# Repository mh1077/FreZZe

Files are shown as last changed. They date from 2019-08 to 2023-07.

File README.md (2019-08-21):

# FreZZe
Fremo Zeit Zeichenempfänger

Das ist ein Zeitzeichen Empfänger für das MRClock Protokoll. Es empfängt MRClock Datentelegramme (Multicast) auf dem WLAN. Der Zeitzeichenempfänger 
wandelt die empfangenen Telegramme um, sodass eine Nebenuhrlinie mit mehreren Uhren betrieben werden kann. Eine Anzeige für Uhr läuft / steht kann realisiert werden, z.B. mit einer rot/grün Ampel aus der Fertigungstechnik.

Viel Spass beim Nachbauen

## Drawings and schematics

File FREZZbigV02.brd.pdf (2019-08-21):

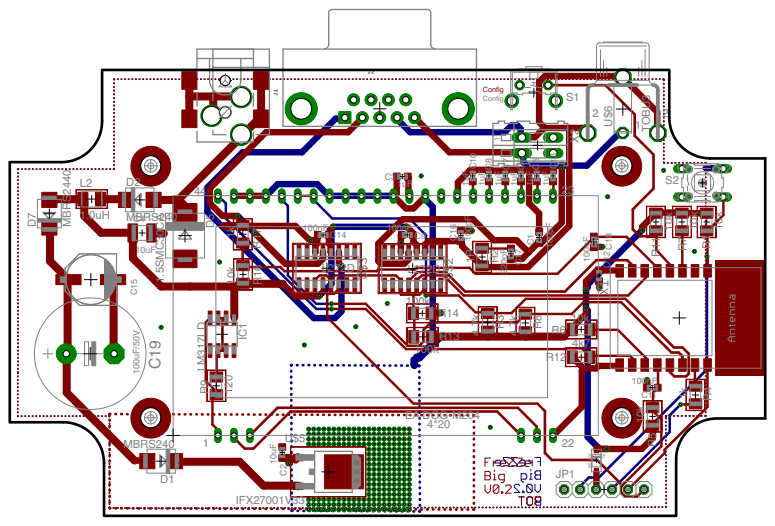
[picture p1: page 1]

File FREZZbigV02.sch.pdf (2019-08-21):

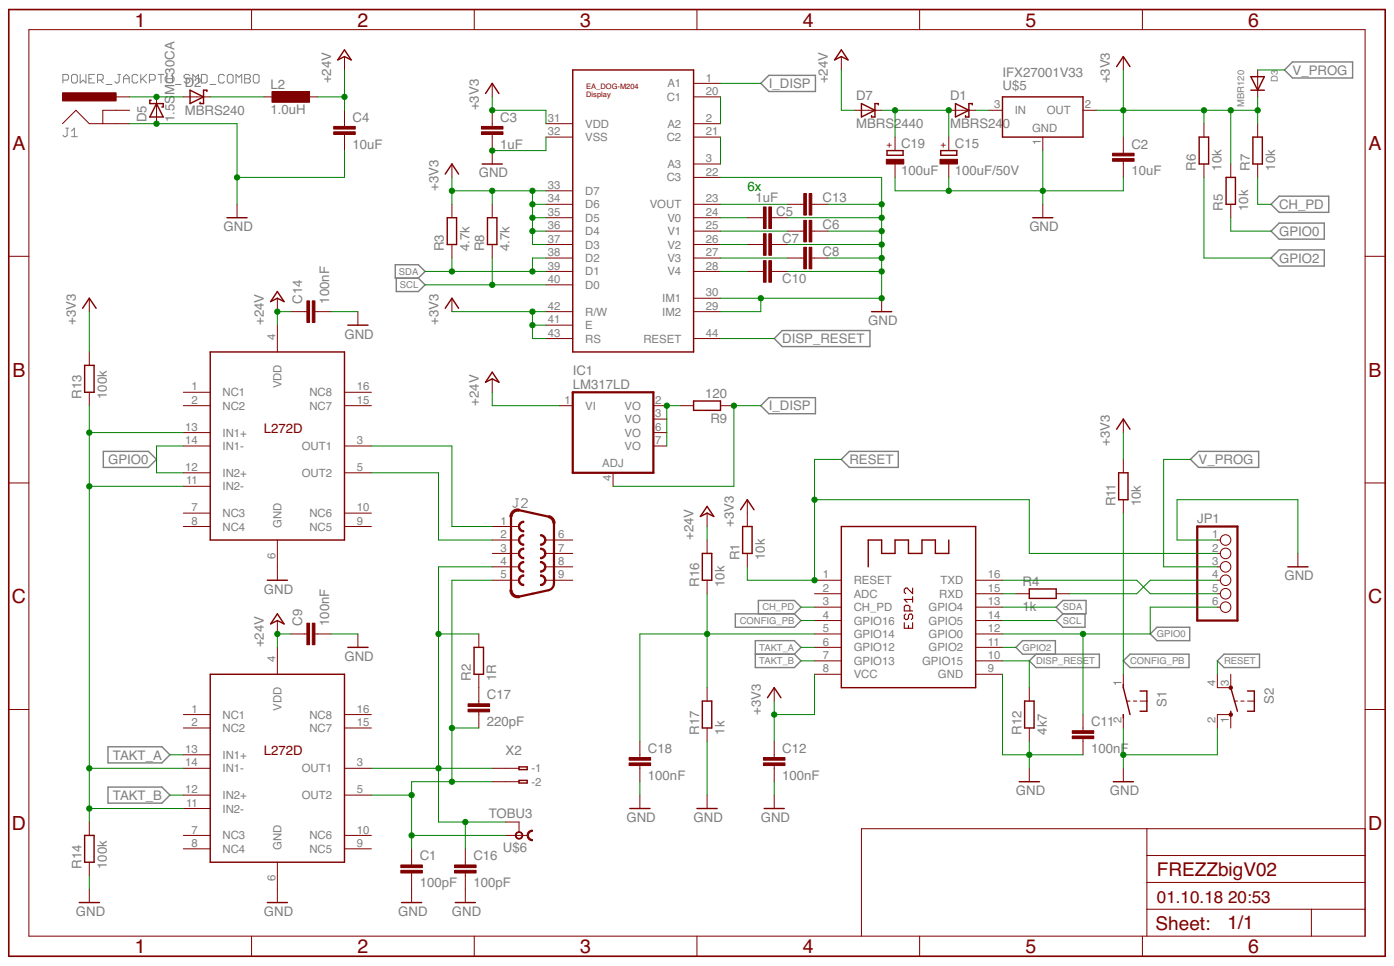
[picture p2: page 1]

34
35 | 24 | C5
36 | 25 | | C6

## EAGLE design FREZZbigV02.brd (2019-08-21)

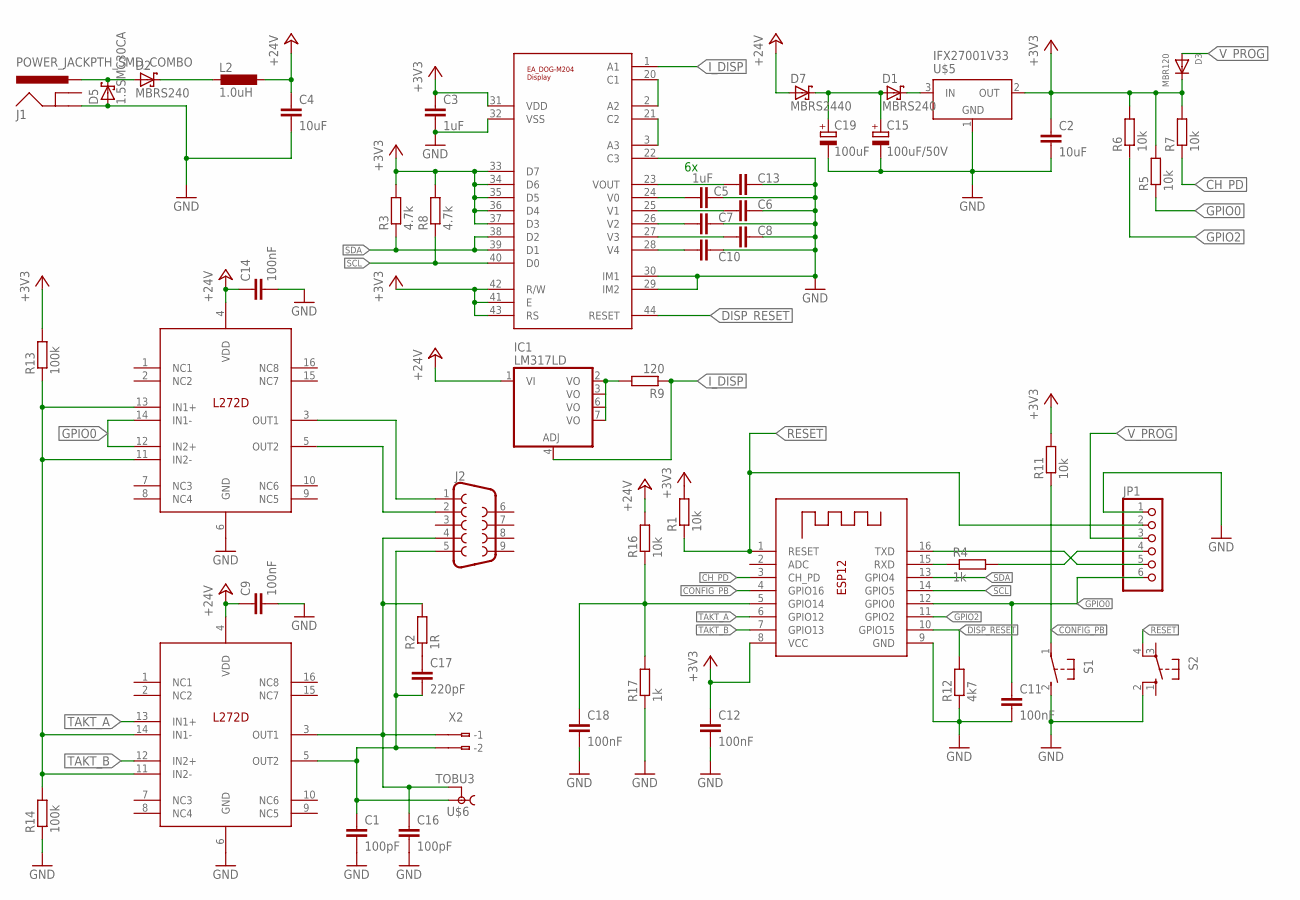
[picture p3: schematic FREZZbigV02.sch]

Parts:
C1, C16: 100pF; C0603K
C2: 10uF; C0603K
C3, C5, C6, C7, C8, C10, C13: 1uF; C0603K
C4: 10uF; C1210K
C9, C11, C12, C14, C18: 100nF; C0603K
C15: 100uF/50V; PANASONIC_F
C17: 220pF; C0603K
C19: 100uF; E7,5-18
D1, D2: MBRS240; SMB
D3: MBR120; SOD-123
D5: 1.5SMC30CA; SMC
D7: MBRS2440; SMB
IC1: LM317LD; SO08
J1: POWER_JACKPTH_SMD_COMBO; POWER_JACK_COMBO
J2: DB9FEMALE; DB9
JP1: PINHD-1X6; 1X06
L2: 1.0uH; L3230M
R1, R5, R6, R7, R11, R16: 10k; M1206
R2: 1R; M1206
R3, R8: 4.7k; M1206
R4, R17: 1k; M1206
R9: 120; M1206
R12: 4k7; M1206
R13, R14: 100k; M1206
S1: 31-XX; B3F-31XX
S2: 10-XX; B3F-10XX
U$1: EA_DOG-M204-DISPLAY; E_DOG-M204_DISPLAY
U$2, U$3: L272D; SO16
U$5: IFX27001V33; TO252
U$6: TOBU3; TOBU3-REICHELT
X1: ESP-12
X2: 233-102

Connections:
$N122: D1.C, U$5.3 (IN)
+3V3: C2.1, C3.1, C12.1, D3.C, R1.2, R3.2, R5.2, R6.2, R7.2, R8.2, R11.2, R13.2, U$1.31 (VDD), U$1.33 (D7), U$1.34 (D6), U$1.35 (D5), U$1.36 (D4), U$1.37 (D3), U$1.41 (E), U$1.42 (R/W), U$1.43 (RS), U$5.2 (OUT), X1.8 (VCC)
+24V: C4.1, C9.1, C14.1, D7.A, IC1.1 (VI), L2.1, R16.2, U$2.4 (VDD), U$3.4 (VDD)
CH_PD: R7.1, X1.3 (CH_PD)
CONFIG_PB: R11.1, S1.1, X1.4 (GPIO16)
DISP_RESET: R12.2, U$1.44 (RESET), X1.10 (GPIO15)
GND: C1.2, C2.2, C3.2, C4.2, C5.1, C6.1, C7.1, C8.1, C9.2, C10.1, C11.2, C12.2, C13.1, C14.2, C15.-, C16.2, C18.2, C19.-, D5.A, J1.GND@1 (GND), JP1.1, R12.1, R14.1, R17.1, S1.2 (S), S2.2 (S1), U$1.22 (C3), U$1.29 (IM2), U$1.30 (IM1), U$1.32 (VSS), U$2.6 (GND), U$3.6 (GND), U$5.1 (GND), X1.9 (GND)
GPIO0: C11.1, JP1.6, R5.1, U$3.12 (IN2+), U$3.14 (IN1-), X1.12 (GPIO0)
GPIO2: R6.1, X1.11 (GPIO2)
I_DISP: IC1.4 (ADJ), R9.1, U$1.1 (A1)
unnamed: JP1.5, X1.16 (TXD)
unnamed: JP1.4, R4.2
unnamed: R4.1, X1.15 (RXD)
unnamed: C13.2, U$1.23 (VOUT)
unnamed: D2.A, D5.C, J1.POWER (PWR)
unnamed: C5.2, U$1.24 (V0)
unnamed: D2.C, L2.2
unnamed: C15.+, C19.+, D1.A, D7.C
unnamed: C17.1, R2.1
unnamed: C16.1, J2.4, R2.2, U$2.3 (OUT1), U$6.2, U$6.2@1 (2), U$6.2@2 (2), X2.B1 (B-1)
unnamed: C6.2, U$1.25 (V1)
unnamed: C1.1, C17.2, J2.5, U$2.5 (OUT2), U$6.1, X2.B2 (B-2)
unnamed: C7.2, U$1.26 (V2)
unnamed: C8.2, U$1.27 (V3)
unnamed: C10.2, U$1.28 (V4)
unnamed: U$1.3 (A3), U$1.21 (C2)
unnamed: U$1.2 (A2), U$1.20 (C1)
unnamed: IC1.2 (VO), IC1.3 (VO), IC1.6 (VO), IC1.7 (VO), R9.2
unnamed: J2.1, U$3.3 (OUT1)
unnamed: J2.2, U$3.5 (OUT2)
unnamed: R13.1, R14.2, U$2.11 (IN2-), U$2.14 (IN1-), U$3.11 (IN2-), U$3.13 (IN1+)
RESET: JP1.2, R1.1, S2.4 (P1), X1.1 (RESET)
SCL: R8.1, U$1.40 (D0), X1.14 (GPIO5)
SDA: R3.1, U$1.38 (D2), U$1.39 (D1), X1.13 (GPIO4)
SHDN: C18.1, R16.1, R17.2, X1.5 (GPIO14)
TAKT_A: U$2.13 (IN1+), X1.6 (GPIO12)
TAKT_B: U$2.12 (IN2+), X1.7 (GPIO13)
V_PROG: D3.A, JP1.3

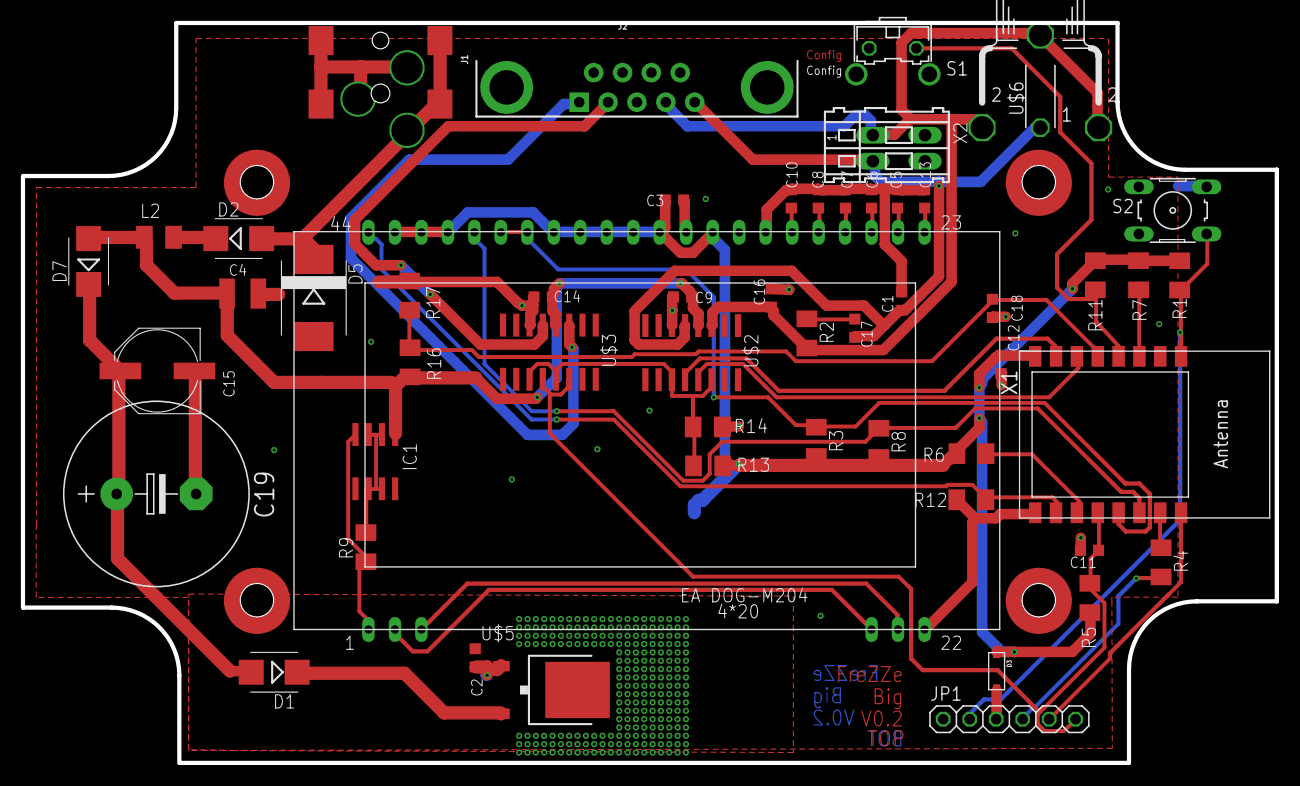
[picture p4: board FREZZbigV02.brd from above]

Board: 2 copper layers, 120.3 x 71.0 mm, 53 parts (0 on the bottom side), 38 nets.

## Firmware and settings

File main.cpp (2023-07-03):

//FreZZe mit EA-Display DOGM204 I2C
//Läuft ab LP V0.2
//Software erstellt 02. September 2017
//Version 1.1 - 06. Januar 2020
//Version 1.2 - 06. April 2020 - Unterstützung für NTP (Normalzeit) eingebaut
//Version 1.3 - 8. Mai 2022 - Wechsel auf Platform IO und Visual Studio Code
//              2. Juli 23 - Letzte Tests V1.3 und Freigabe
//              Achtung! Für den PufferC C15 bzw. C15 wird neu 1000uF benötigt, sonst funktioniert das automatische 
//                       Abspeichern bei Spannungsverlust nicht mehr zuverlässig!

#define VERSION "V1.3"

//Includes Librarys:
#include <Arduino.h>
#include "FS.h"                   //this needs to be first, or it all crashes and burns...
#include <LittleFS.h>

#include "TickerScheduler.h"      //Ticker

#include <ESP8266WiFi.h>          //https://github.com/esp8266/Arduino

//needed for library
#include <ESP8266WebServer.h>
#include <WiFiManager.h>          //https://github.com/tzapu/WiFiManager

#include <ArduinoJson.h>          //https://github.com/bblanchon/ArduinoJson
#include <StreamUtils.h>

//needed for NTP 
#include <TimeLib.h>
#include <WiFiUdp.h>
#include <Timezone.h>             //by Jack Christensen, not included in the Arduino IDE !!!

// Communication for the Display
#include <Wire.h>

#include <String>

//Eigene Funktionen
#include "FreZZe.h"

//Defines for Pins
#include "FreZZe_PINS.h"

//Defines für Zeiten
#include "FreZZe_TIMES.h"

//Defines für das Display
#define I2C_ADRESS 0x3D
#define DISPLAYKONTRAST   10      //nach Test ein guter Wert

//Variablen für die LED Anzeige
int LEDStatus = 0;                //LED Status wird durch das Programm gemäss den oben angegebenen Defines gesetzt und durch die Task LED() wird die LED angesteuert
int LEDStatusIntern = 0;          //LED Status intern für die LED Routine
int LEDStatusCounter = 0;         //LED Status Counter zum zählen bis zum nächsten Statuswechsel
int LEDPeriodCounter = 0;         //Dient als Zähler für das LEDaus vorbereiten (Periodenlänge LED an)....

//define your default values here, if there are different values in config.json, they are overwritten.
char mrc_multicast[40] = "239.50.50.20";
char mrc_port[6] = "2000";

//char array for the protokollhandler 
char c_clock_hour[15] = "03";
char c_clock_minute[15] = "02";
char c_clock_sek[15] = "04";
char c_time[15] = "0";
char c_speed[15] = "0";

//Strings 
String esp_chipid;

//Displaybuffer
char SBuffer[4][80] = {{ "11111111111111111111" },{ "22222222222222222222" },{ "33333333333333333333" },{ "44444444444444444444" }};

//TEMP Variable for Display
char ctempd[200];
String stempd;

//VARIABLEN für die IP-Addressenübernahme
String sIPAddressinformertime;    //Letzte bekannte IP-Adresse, welche akzeptiert wurde
String sIPAddressjustrecieved;    //aktuelle empfangene IP-Adresse
String sIPAddresstemprecieved;    //diese IP-Addresse wird nach einer Zeit akzeptiert und zu sIPAddressinformertime übernommen
int iCounterIPAddress = 0;        //Counter zur Übernahme einer neuen IP-Adresse

//Daten aus dem Protokoll
int  clock_h = 0;   // Sollzeit Stunde
int  clock_m = 0;   // Sollzeit Minute
int  clock_s = 0;   // Sollzeit Sekunde
int  clock_speed = 1; //Zeitverkürzung
bool clock_aktiv = false; //Läuft die Uhr oder steht sie? 

int  tochter_h = 0; // Istzeit auf der 12h Tochteruhr (Stunden)
int  tochter_m = 0; // Istzeit auf der 12h Tochteruhr (Minuten)

int  itelecnt = 0; //Zähler wird als Watchdog für den Telegrammempfang, wird beim Telegrammenpfang 
                   //auf den TELECNTSTART Wert gesetzt und in jeder Schleife um ein reduziert.
                   //ist er 0, wird die Ampel auf rot geschaltet.
#define TELECNTSTART 6000 //Zeitbasis = der Delay() Wert in der Loop Schleife! 1 entspricht 10ms bei Delay(10)

//NTP Variablen
char ntpserver[40] = "ntp.metas.ch";         //NTPServer
unsigned int localPort = 8888;               // local port to listen for UDP packets
const int timeZone = 0;                      // UTC
double dCounterToNTP;                        //if no MRCLOCK telegramm is recieved, the conter gets decressed, on ZERO the NTP time is displayed
const int NTP_PACKET_SIZE = 48;              // NTP time is in the first 48 bytes of message
byte packetBufferNTP[NTP_PACKET_SIZE];       //buffer to hold incoming & outgoing packets

//Timezone
//Central European Time (Frankfurt, Paris)
TimeChangeRule CEST = { "CEST", Last, Sun, Mar, 2, 120 };     //Central European Summer Time
TimeChangeRule CET = { "CET ", Last, Sun, Oct, 3, 60 };       //Central European Standard Time
Timezone CE(CEST, CET);
TimeChangeRule *tcr;        //pointer to the time change rule, use to get the TZ abbrev
time_t utc, local;
time_t prevDisplay = 0;     // when the digital clock was displayed

//Statemaschine für TochterUhrStellen Routine
int  SM = 0;                  // Statemaschine Status
int  SMC = 0;                 // Statemaschine Counter
bool FlagTUStellen;           // Flag ist gesetzt, falls die Tochteruhr einen Tick machen soll
bool FlagTUStellglied;        // Flag wiederspiegelt den Ausgang des TU Stellglieds

//Rücksetztaste
bool FlagButtonPresed = false;
int  CounterButtonPressed;

//Tickerscheduler Objekt

TickerScheduler ts(10);

//flag for saving data
bool shouldSaveConfig = false;

//flag for sleep mode 
bool sleep = false;
bool flag_message_recieved = true;
bool flag_wrongIP = false;

//flag for clock ticks
bool bClockBad = true;  //true on startup, until one falid Clockmessage war recieved

//WifiUDP Class
WiFiUDP wifiUDPMRC;     //für MRClock Telegramme
WiFiUDP wifiUDPNTP;     //für NTP Telegramme

const int MRC_PACKET_SIZE = 2024; // NTP time stamp is in the first 48 bytes of the message

char packetBuffer[ MRC_PACKET_SIZE ]; //buffer to hold incoming and outgoing packets

int nLength = 0;

int time_hour = 0;

int time_minute = 0;

unsigned long millisAfterISR = 0;

//WiFiManager
  //Das Object wird auch noch im LOOP benötigt um die Config zu löschen.... 
  WiFiManager wifiManager;
  //Die beiden Parameter werden durch ein Callback verändert, deswegen müssen sie Global definiert sein
  WiFiManagerParameter custom_time_hour();
  WiFiManagerParameter custom_time_minute();

void setup() {
  // put your setup code here, to run once:
  Serial.begin(115200);
  Serial.println("Starting up!");

  LED(LEDOff);               // Am Anfang ist die LED aus....

  //ChipID?
  esp_chipid = String(ESP.getChipId());

  //Identify
  Serial.print("Tochteruhrempfänger TUE ");
  Serial.print(VERSION);
  Serial.print(" ESP - ChipID = ");
  Serial.println(esp_chipid); 

  Serial.println("Configuring Pins and Interrupts");

  //Variablen initialisieren
  FlagTUStellen = false;  //FlagTUStellen initialisieren
  SM = 1;
  SMC = 0;                //Statemaschine für die Taktausgabe initialisieren
  
  delay(500);

  //Display initialisieren
  //I2C Pins konfigurieren

  pinMode(DISP_RESET, OUTPUT);
  digitalWrite(DISP_RESET, LOW);
  delay(500);
  digitalWrite(DISP_RESET, HIGH);
  delay(500);
  
  //I2C initialisieren, Display init
  Wire.begin();

  Wire.setClock(200000L);
  
  LCD_Init();

  delay(10);

  // Buffer          "1   5    10   15  19"
  strcpy(SBuffer[0], "FREMO MRCLOCK       ");
  strcpy(SBuffer[1], "Reciever        ");
  strcat(SBuffer[1], VERSION); 
  strcpy(SBuffer[2], "                    ");
  strcpy(SBuffer[3], "INIT.               ");

  LCD_Refresh();

  delay(1000);

  //WiFi.setAutoReconnect(false);
  WiFi.persistent(true); // Wird gebraucht damit das Flash nicht zu oft beschrieben wird.
  WiFi.setAutoReconnect(true);
  
  //Pins konfigurieren
  //GPIO #12 (TaktA)
  //GPIO #13  (TaktB)
  //GPIO #16 (Input für Config Pushbutton) Bei MRC_REC = 5!
  //GPIO #2 = blue LED on ESP
  //GPIO #14 = Interrupt für Spannungseinbruch -> Interrupt wird an der fallenden Flanke ausgelöst
  //GPIO #15 Reset des Displays
  //GPIO #0 Ampel grün/rot

  pinMode(TAKTA, OUTPUT);
  pinMode(TAKTB, OUTPUT);
  pinMode(CONFIGPB, INPUT);
  pinMode(BLED, OUTPUT);
  pinMode(AMPEL, OUTPUT);

  digitalWrite(AMPEL, HIGH);  //Ampel auf Rot stellen

  //Konfiguration des InterruptPINs 
  //Sobald eine + Spannung gemessen wird, wird der Interrupt aktiviert, wird LOW gemessen, dann ist der Interrupt deaktiviert
  pinMode(INT, INPUT);
  delay(10);

  if(digitalRead(INT) == HIGH){     //Interrupt wird aktiviert
    Serial.println("Interrupteingang verdrahtet, wird benutzt!");
    attachInterrupt(digitalPinToInterrupt(INT), ISRSaveData, FALLING);
  }
  else{
    Serial.println("Interrupteingang ist nicht verdrahtet, wird nicht benutzt!");
    pinMode(INT, INPUT_PULLUP);
  }

  digitalWrite(BLED, HIGH);

  ts.add(5, 10, [&](void*) { LEDTS(); }, nullptr, false);

  if(ts.enable(5)){
    Serial.println("LEDTS() = 5 enabled");
  }

  LED(LEDBlinkOnce);         // LED einen Flash blinken -> 1. Blinkimpuls

  //clean FS, for testing
  //SPIFFS.format();
  //SPIFFS.remove("/config.json");
  //SPIFFS.remove("/config2.json");
  
  //read configuration from FS json
  Serial.println("mounting FS...");

  // Falls das Filesystem noch nicht formatiert ist, wird es hier automatisch gemacht.
  if(LittleFS.begin()){
    Serial.println("FS ok!");
  } else {
    LittleFS.format();
    Serial.println("FS formated");
  }

  LED(LEDBlinkOnce);     // LED einen Flash blinken  -> 2. Blinkimpuls

  //Filesystem mounten und Datei suchen, wenn Datei nicht vorhanden dann Neuerstellung
  if (LittleFS.begin()) {
    Serial.println("mounted file system");
    if (LittleFS.exists("/config.json")) {
      //file exists, reading and loading
      Serial.println("reading config file");
      File configFile = LittleFS.open("/config.json", "r");
      if (configFile) {
        Serial.println("opened config file");
        //size_t size = configFile.size();

        DynamicJsonDocument jsonDocument(2048);

        // ArduinoJson 6
        ReadLoggingStream loggingStream(configFile, Serial);
        DeserializationError error = deserializeJson(jsonDocument, configFile);
        Serial.print("\n-deserializeJson() -> output:");
        Serial.print(error.c_str());

        /*
        // Allocate a buffer to store contents of the file.
        std::unique_ptr<char[]> buf(new char[size]);

        configFile.readBytes(buf.get(), size);
        DynamicJsonDocument jsonDocument(size);

        Serial.println("ConfigFile:");
        Serial.println(configFile.read());

        // ArduinoJson 6
        DeserializationError error = deserializeJson(jsonDocument, configFile);
        */
        
        if (!error) 
        {
          Serial.println("\nparsed json =>  ");

          /*
          strcpy(ntpserver, jsonDocument["ntp_server"]);
          strcpy(mrc_multicast, jsonDocument["mrc_multicast"]);
          strcpy(mrc_port, jsonDocument["mrc_port"]);
          strcpy(c_clock_hour, jsonDocument["clock_hour"]);
          strcpy(c_clock_minute, jsonDocument["clock_minute"]);
          if(jsonDocument["FlagTUStellglied"] == "true")
          {
            FlagTUStellglied = true;
            digitalWrite(TAKTA, LOW);
            digitalWrite(TAKTB, LOW);
            Serial.print("FlagTUStellglied = true");
          } else {
            FlagTUStellglied = false;
            digitalWrite(TAKTA, HIGH);
            digitalWrite(TAKTB, HIGH); 
            Serial.print("FlagTUStellglied = false");
          }

          */

          JsonVariant jvntpserver = jsonDocument["ntp_server"];
          if (!jvntpserver.isNull()) {
            Serial.print(" ntpserver=");
            Serial.print(jvntpserver.as<const char*>());
            strcpy(ntpserver, jvntpserver.as<const char*>());
          } else {
            strcpy(ntpserver, "ntp.metas.ch");
            Serial.print(" no value => ntp.metas.ch");
          }

          JsonVariant jvmrc_multicast = jsonDocument["mrc_multicast"];
          Serial.print(", mrc_multicastadress=");
          if (!jvmrc_multicast.isNull()) {
            Serial.print(jvmrc_multicast.as<const char*>());
            strcpy(mrc_multicast, jvmrc_multicast.as<const char*>());
          } else {
            strcpy(mrc_multicast, "239.50.50.20");
            Serial.print(" no value => 239.50.50.20");
          }

          JsonVariant jvmrc_port = jsonDocument["mrc_port"];
          Serial.print(", mrc_port=");
          if (!jvmrc_port.isNull()) {
            Serial.print(jvmrc_port.as<const char*>());
            strcpy(mrc_port, jvmrc_port.as<const char*>());
          } else {
            strcpy(mrc_port, "2000");
            Serial.print("no value => 2000");
          }

          JsonVariant jvc_clock_hour = jsonDocument["clock_hour"];
          Serial.print(", clock_hour=");
          if (!jvc_clock_hour.isNull()) {
            Serial.print(jvc_clock_hour.as<int>());
            itoa(jvc_clock_hour, c_clock_hour, 10);
            //strcpy(c_clock_hour, jvc_clock_hour.as<char*>());
          } else {
            strcpy(c_clock_hour, "0");
            Serial.print("no value => 0");
          }

          JsonVariant jvc_clock_minute = jsonDocument["clock_minute"];
          Serial.print(", clock_minute=");
          if (!jvc_clock_minute.isNull()) {
            Serial.print(jvc_clock_minute.as<int>());
            itoa(jvc_clock_minute, c_clock_minute, 10);
            //strcpy(c_clock_minute, jvc_clock_minute.as<char*>());
          } else {
            strcpy(c_clock_minute, "0");
            Serial.print("no value => 0");
          }

          JsonVariant jvc_flagTUStellglied = jsonDocument["FlagTUStellglied"];
          Serial.print(", FlagTUStellglied=");
          if(!jvc_flagTUStellglied.isNull()){
            if(jsonDocument["FlagTUStellglied"] == true){
              FlagTUStellglied = true;
              digitalWrite(TAKTA, LOW);
              digitalWrite(TAKTB, LOW);
              Serial.print("true");
            }else{
              FlagTUStellglied = false;
              digitalWrite(TAKTA, HIGH);
              digitalWrite(TAKTB, HIGH); 
              Serial.print("false");
            }
          }
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
void loop() 
{
  // loop checks for:
  // - MRCLOCK Telegramm, or
  // - NTP 
  // MRCLOCK has priority to NTP telegramms, if there were no MRCLOCK Telegramm for WaittimeNTPSync [seconds] then, the 
  // Slaveclock is syncronised to NTP Clock until the first MRCLOCK telegramm comes in...
  
  // If a MRCLOCK Telegramm is recieved:
  if (int packetsize = wifiUDPMRC.parsePacket()) 
  {
    dCounterToNTP = WaittimeNTPSync;           // Counter updaten
    Serial.println("@.");
    flag_wrongIP = false;
    // We've received a packet, read the data from it
    wifiUDPMRC.read(packetBuffer, packetsize); // read the packet into the buffer

    //Search for Message like "clock=10:32:35"
    for(unsigned long i=0; i < sizeof(packetBuffer); i++)
    {
      if( packetBuffer[i] == 'c' &&
          packetBuffer[i+1] == 'l' &&
          packetBuffer[i+2] == 'o' &&
          packetBuffer[i+3] == 'c' &&
          packetBuffer[i+4] == 'k' &&
          packetBuffer[i+5] == '=')
      {
        c_time[0] = packetBuffer[i+6];
        c_time[1] = packetBuffer[i+7];
        c_time[2] = packetBuffer[i+8];
        c_time[3] = packetBuffer[i+9];
        c_time[4] = packetBuffer[i+10];
        c_time[5] = packetBuffer[i+11];
        c_time[6] = packetBuffer[i+12];
        c_time[7] = packetBuffer[i+13];
        c_time[8] = packetBuffer[i+14];
            
        // Time Char Array zerlegen
        bool clear_h = true;
        bool clear_m = false;
        bool clear_s = false;
            
        for(int ii=0; ii < 15; ii++)
        {
          if( !clear_h && !clear_m && clear_s)
          {                
            if( c_time[ii] == 0)
            {
              clear_m = false;
              clear_s = false;
              c_clock_hour[ii] = ' ';
              c_clock_minute[ii] = ' ';
              c_clock_sek[ii] = ' ';
            } else {
              c_clock_hour[ii] = ' ';
              c_clock_minute[ii] = ' ';
              c_clock_sek[ii] = c_time[ii];
            }
          }
          if( !clear_h && clear_m && !clear_s) 
          {                
            if( c_time[ii] == ':')
            {
              clear_m = false;
              clear_s = true;
              c_clock_hour[ii] = ' ';
              c_clock_minute[ii] = ' ';
              c_clock_sek[ii] = ' ';
            } else {
              c_clock_hour[ii] = ' ';
              c_clock_minute[ii] = c_time[ii];                  
              c_clock_sek[ii] = ' ';
            }
          }
          if( clear_h && !clear_m && !clear_s)
          {                
            if( c_time[ii] == ':')
            {
              clear_h = false;
              clear_m = true;
              c_clock_hour[ii] = ' ';
              c_clock_minute[ii] = ' ';
              c_clock_sek[ii] = ' ';
            } else {
              c_clock_hour[ii] = c_time[ii];
              c_clock_minute[ii] = ' ';
              c_clock_sek[ii] = ' ';
            }
          }
        }
  
        clock_h = atoi(c_clock_hour);
        clock_m = atoi(c_clock_minute);
        clock_s = atoi(c_clock_sek);

        Serial.print("Empfangenes Zeitzeichen:");
        Serial.print(clock_h);
        Serial.print(":");
        Serial.print(clock_m);
        Serial.print(":");
        Serial.println(clock_s);
      }
    }
     
    //Search for Message like "speed=5"
    for(unsigned long i=0; i < sizeof(packetBuffer); i++)
    {
      if( packetBuffer[i] == 's' &&
          packetBuffer[i+1] == 'p' &&
          packetBuffer[i+2] == 'e' &&
          packetBuffer[i+3] == 'e' &&
          packetBuffer[i+4] == 'd' &&
          packetBuffer[i+5] == '=')
      {
        if(packetBuffer[i+6] == '\n' || packetBuffer[i+6] == '\r')
        {
          c_speed[0] = '\0';
        } else c_speed[0] = packetBuffer[i+6];
        if(packetBuffer[i+7] == '\n' || packetBuffer[i+7] == '\r')
        {
          c_speed[1] = '\0';
        } else c_speed[1] = packetBuffer[i+7];
        if(packetBuffer[i+8] == '\n' || packetBuffer[i+8] == '\r')
        {
          c_speed[2] = '\0';
        } else c_speed[2] = packetBuffer[i+8];
        if(packetBuffer[i+9] == '\n' || packetBuffer[i+9] == '\r')
        {
          c_speed[3] = '\0';
        } else c_speed[3] = packetBuffer[i+9];
        
        c_speed[4] = '\0';

        Serial.print("Speed=");
        Serial.println(c_speed);

        Serial.print("Speed_int=");
        clock_speed = atoi(c_speed);
        Serial.println(clock_speed);
      }
    }

    //Search for Message like "active=yes|no"
    for(unsigned long i=0; i < sizeof(packetBuffer); i++)
    {
      if( packetBuffer[i] == 'a' &&
          packetBuffer[i+1] == 'c' &&
          packetBuffer[i+2] == 't' &&
          packetBuffer[i+3] == 'i' &&
          packetBuffer[i+4] == 'v' &&
          packetBuffer[i+5] == 'e' &&
          packetBuffer[i+6] == '=')
      {
        if( packetBuffer[i+7] == 'y' &&
            packetBuffer[i+8] == 'e' &&
            packetBuffer[i+9] == 's')
        {
          clock_aktiv = true;
          digitalWrite(AMPEL, LOW);  //Ampel auf Grün stellen
          itelecnt = TELECNTSTART;
        } else {
          digitalWrite(AMPEL, HIGH);  //Ampel auf Rot stellen
          clock_aktiv = false;
        }
          
        if(clock_aktiv)
        {
          Serial.println("Uhr läuft!");
        } else Serial.println("Uhr steht!");
      }
    }

    // recieving one message!
    Serial.println("; Ende der Message");
    flag_message_recieved = true;
  }

  //Stimmt die Anzeige auf der Ampel?
  if(clock_aktiv)
  {
    if(!itelecnt)
    {
      digitalWrite(AMPEL, HIGH);  //Ampel auf Rot stellen
      clock_aktiv = false;
    } else itelecnt--;
  }
  
  // Ist der Taster gedrückt?
  ConfigButton();

  //Soll auf NTP-Zeitzeichenempfang umgeschaltet werden?
  if(dCounterToNTP == 0)
  {
    //jetzt wird die NTP Zeit an der Tochteruhr angezeigt...
    if (timeStatus() != timeNotSet) 
    {
      if (now() != prevDisplay) 
      { 
        //update the display only if time has changed
        prevDisplay = now();

        local = CE.toLocal(now(), &tcr);
        
        Serial.print("Hour=");
        Serial.print(hour(local), DEC);
        Serial.print("Minute=");
        Serial.print(minute(local), DEC);
        Serial.print("Seconds=");
        Serial.println(second(local), DEC);
  
        clock_h = hour(local);
        clock_m = minute(local);
        clock_s = second(local);
      }
    }
  } else dCounterToNTP--;
  
  //Tasks bedienen
  yield();
  ts.update();
  Serial.print(".");
  delay(10);
}

// Unterfunktionen

//WifiManager
//callback notifying us of the need to save config
void saveConfigCallback () {
  Serial.println("Should save config");
  shouldSaveConfig = true;
}

// CALLBACK wird mit dem Starten der Configurationsseite aufgerufen und stellt die Uhr um zwei Ticks weiter, damit sie mit der internen Uhr synchron läuft
void APCallback(WiFiManager *myWiFiManager){

  String temp;
  String temp1="               ";
  
  // Buffer          "1   5    10   15  19"
  strcpy(SBuffer[2], "CaptivePortal runing");
  strcpy(SBuffer[3], "SSID:");

  temp = myWiFiManager->getConfigPortalSSID();
  strncat(SBuffer[3], temp1.c_str(), 15-strlen(temp.c_str())); 
  strncat(SBuffer[3], temp.c_str(), strlen(temp.c_str()));
  LCD_Refresh();
  
  // Some other things to do?
  WiFiManagerParameter custom_time_hour("clock_hour", "zulaessige Werte (00-11)", c_clock_hour, 15);
  WiFiManagerParameter custom_time_minute("clock_minute", "zulaessige Werte (00-59)", c_clock_minute, 15);
}
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

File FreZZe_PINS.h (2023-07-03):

// FreZZe_PINS.h
// Definitionen für die Pins

#define TAKTA            12       //SPI MISO = GPIO #12 (TaktA)
#define TAKTB            13       //GPIO #13  (TaktB)
#define CONFIGPB         16       //GPIO #16 (Input für Config Pushbutton) Bei MRC_REC = 5!
#define BLED              2       //GPIO #2 = blue LED on ESP
#define INT              14       //GPIO #14 = Interrupt für Spannungseinbruch -> Interrupt wird an der fallenden Flanke ausgelöst
#define DISP_RESET       15       //GPIO #15 Reset des Displays
#define AMPEL            0        //GPIO #0 Ampel grün/rot

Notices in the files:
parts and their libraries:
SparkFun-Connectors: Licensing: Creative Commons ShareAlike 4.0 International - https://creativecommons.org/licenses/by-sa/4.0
